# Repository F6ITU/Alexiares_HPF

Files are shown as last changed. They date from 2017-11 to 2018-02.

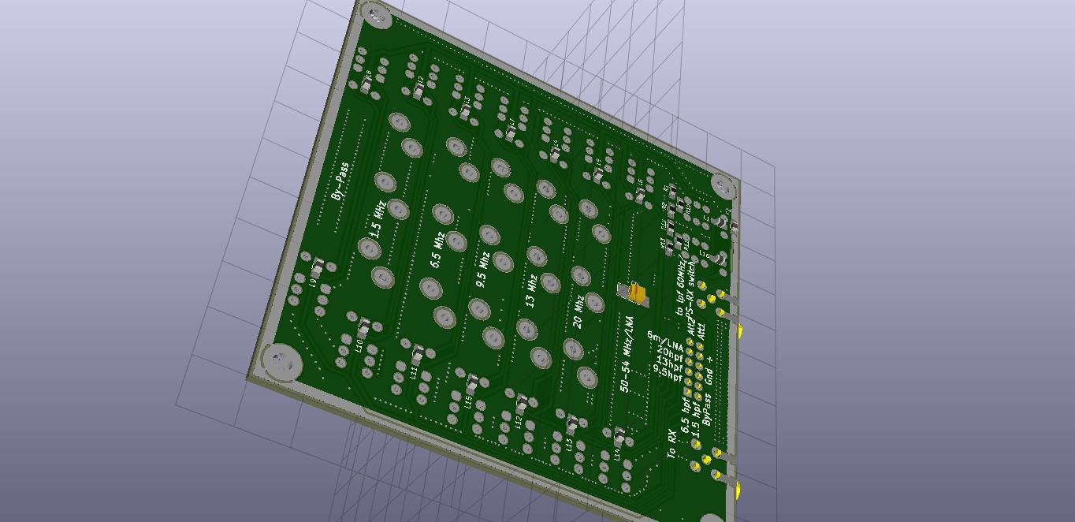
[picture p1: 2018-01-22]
HPF_bottom.jpg

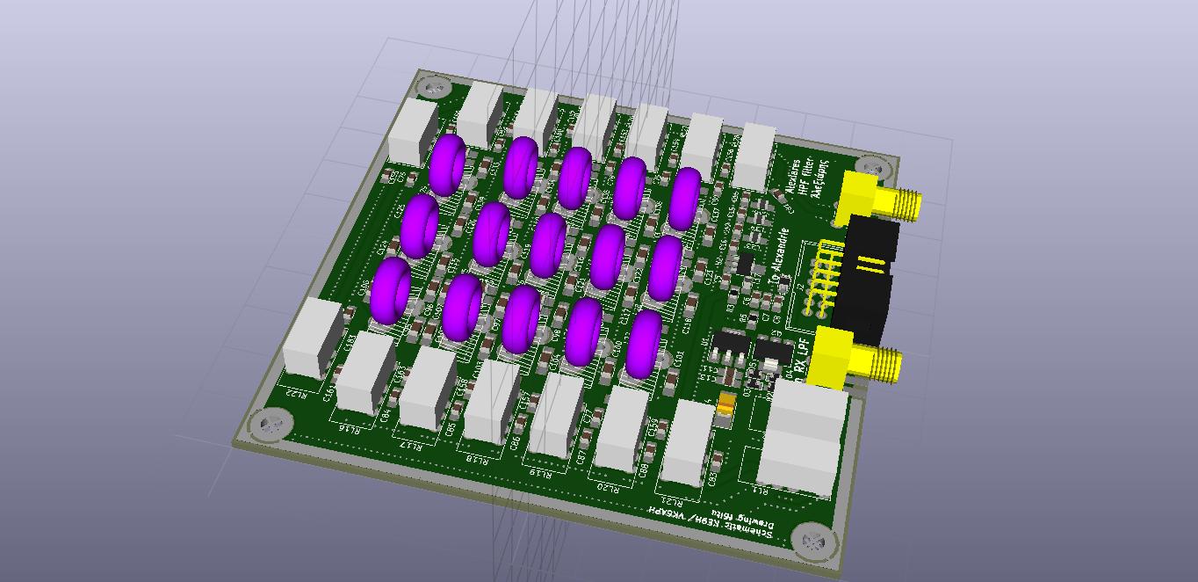
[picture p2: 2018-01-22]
HPF_top.jpg

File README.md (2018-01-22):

# Alexiares_HPF
This repository contains the High Pass Filter project of the OpenHPSDR Alexiares frontend

This work is protected by the TAPR Open Hardware Licence https://www.tapr.org/ohl.html

Original work by Graham Haddock, KE9H and Phil Harman, VK6APH.

for more informations, please refer to 

https://wiki.electrolab.fr/Projets:Lab:2017:Peripheriques_Angelia

3D image of the board are stored on this repo

HPF_top.jpg

HPF_bottom.jpg

Bom is available in CSV format

A separate BOM in XLS format is dedicated to filter capacitors

Note that ALL filter caps must be C0G or at least NP0 quality

Schematics, pcb design, modules and libs are in Kicad format

Gerber files are fully compatible with Protel 4.6 format

Board's dimensions are oversized to fit the 5x10 and 10x10cm size of all board of the Hermes project under Kicad:

* Alexandrie (Ἀλεξάνδρεια), Alexiares SPI interface
* Alexi2C ( Ἄλεξις), Alternate Alexiares I2C interface
* Alexiares_lpf (Ἀλεξιάρης) Alexiares low pass filter
* Alexiares_hpf (Ἀλεξιάρης) Alexiares high-pass filter
* Alexiares_Coax_Out (Ἀλεξιάρης ) Alexiares antenna switch boards
* Télémaque (Τηλέμαχος),  SSPA U/V/C°/Refl/FWD sensor for the Mentor board 
* Mentor (Μέντωρ) Micro-controler unit(MCU) and security module controling Telemaque informations
* Ulysse ou Odysseus (Ὀδυσσεύς), medium power reflectometer for the Telemaque/Mentor set
* Themis (Θέμις), low power bidirectionnal reflectometer with pre-distorsion (pure signal) output
* Aiôn (αἰών), 10 MHz low drift, low phase noise clock (general purpose)
* Hébé (Ἥβη), EER control system for high efficiency power amp

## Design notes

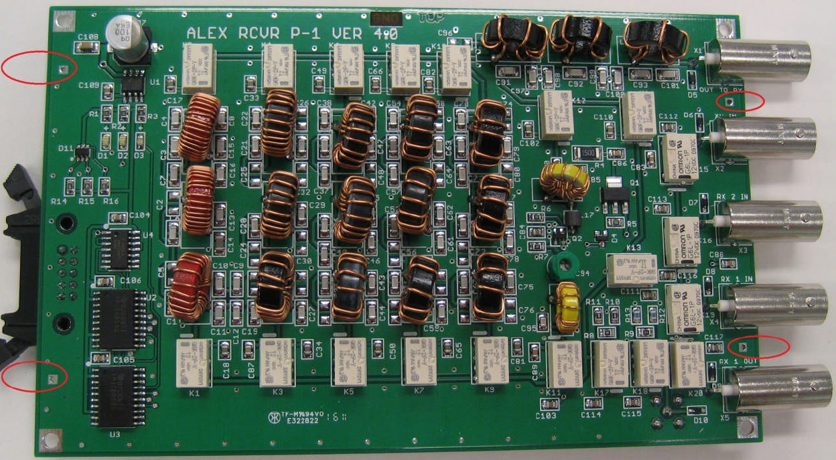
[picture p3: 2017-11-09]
Datasheet/alex hpf tapr.PNG

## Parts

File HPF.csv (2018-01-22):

Source: | C:/Users/Marco/Documents/Kicad/Projets/Alexiares_HPF/HPF.sch
Date: | 09/01/2018 09:03
Tool: | Eeschema 4.0.7
Generator: | C:/Program Files/KiCad/bin/scripting/plugins/bom_csv_grouped_by_value_with_fp.py
Component Count: | 174
Ref | Qnty | Value | Footprint
C7, | 1 | 100n | Capacitors_SMD:C_0805_HandSoldering
C8, | 1 | 1n | Capacitors_SMD:C_0805_HandSoldering
C9, C14, | 2 | 10uf | Capacitors_Tantalum_SMD:CP_Tantalum_Case-B_EIA-3528-21_Hand
C11, | 1 | 10p | Capacitors_SMD:C_0805_HandSoldering
C15, C12, | 2 | 60p | Capacitors_SMD:C_0805_HandSoldering
C16, C10, C13, | 3 | 100p | Capacitors_SMD:C_0805_HandSoldering
C81, C80, C79, C78, C77, C76, C159, C157, C158, C162, C161, C160, C82, C163, C156, C83, C155, C90, C154, C88, C153, C87, C152, C86, C151, C85, C150, C84, C4, C1, C3, C2, C5, C6, | 34 | 10n | Capacitors_SMD:C_0805_HandSoldering
C93, C116, C109, | 3 | 330p | Capacitors_SMD:C_1206_HandSoldering
C97, C107, C102, C96, C95, C183, | 6 | 2.2n | Capacitors_SMD:C_1206_HandSoldering
C98, C143, C144, C133, | 4 | 1.8n | Capacitors_SMD:C_1206_HandSoldering
C100, C115, C106, | 3 | 1.5n | Capacitors_SMD:C_1206_HandSoldering
C101, | 1 | 1.2n | Capacitors_SMD:C_1206_HandSoldering
C117, C137, C139, | 3 | 270p | Capacitors_SMD:C_1206_HandSoldering
C118, C94, C127, C110, C104, C103, | 6 | 220p | Capacitors_SMD:C_1206_HandSoldering
C121, | 1 | 100p | Capacitors_SMD:C_1206_HandSoldering
C123, C111, | 2 | 33p | Capacitors_SMD:C_1206_HandSoldering
C125, | 1 | 1n | Capacitors_SMD:C_1206_HandSoldering
C128, C140, | 2 | 68p | Capacitors_SMD:C_1206_HandSoldering
C129, C112, C120, | 3 | 180p | Capacitors_SMD:C_1206_HandSoldering
C130, C122, | 2 | 47p | Capacitors_SMD:C_1206_HandSoldering
C131, C113, | 2 | 120p | Capacitors_SMD:C_1206_HandSoldering
C132, C108, | 2 | 22p | Capacitors_SMD:C_1206_HandSoldering
C134, | 1 | 680 | Capacitors_SMD:C_1206_HandSoldering
C136, C126, | 2 | 390p | Capacitors_SMD:C_1206_HandSoldering
C145, C91, | 2 | 820p | Capacitors_SMD:C_1206_HandSoldering
C146, C124, | 2 | 680p | Capacitors_SMD:C_1206_HandSoldering
C147, | 1 | 68pC | Capacitors_SMD:C_1206_HandSoldering
C148, C135, C119, | 3 | 560p | Capacitors_SMD:C_1206_HandSoldering
C149, C92, | 2 | 470p | Capacitors_SMD:C_1206_HandSoldering
D1, | 1 | diode | Diodes_SMD:D_1206
D2, D3, D5, D4, | 4 | D | Diodes_SMD:D_0805
J2, | 1 | Conn_01x12 | Connect:IDC_Header_Straight_12pins
J3, J1, | 2 | CONN_COAXIAL | Connectors:SMA_THT_Jack_Straight
J5, J4, | 2 | CONN_COAXIAL | SMA_PINS:SMA_EDGE_NRW
L16, L2, L10, L5, L13, L3, L11, L4, L12, L7, L15, L6, L14, L8, L9, L1, | 16 | Choke | Inductors_SMD:L_0805_HandSoldering
L18, | 1 | 3.5u | T50:T50_V_THT
L19, | 1 | 1.14uH | T50:T50_V_THT
L21, | 1 | 562nH | T50:T50_V_THT
L22, | 1 | 311nH | T50:T50_V_THT
L23, L34, L35, L17, | 4 | 220n | Inductors_SMD:L_0805_HandSoldering
L28, | 1 | 434nH | T50:T50_V_THT
L29, L24, | 2 | 6.25u | T50:T50_V_THT
L30, L25, | 2 | 1.55uH | T50:T50_V_THT
L31, L26, | 2 | 940nH | T50:T50_V_THT
L32, L27, L20, | 3 | 650nH | T50:T50_V_THT
L33, | 1 | 511nH | T50:T50_V_THT
Q2, | 1 | zvp2106G | TO_SOT_Packages_SMD:SOT-223
R1, R2, | 2 | 100R | Resistors_SMD:R_0805_HandSoldering
R3, | 1 | 18 | Resistors_SMD:R_0805_HandSoldering
R5, | 1 | 10k | Resistors_SMD:R_0805_HandSoldering
R10, | 1 | 75R | Resistors_SMD:R_0805_HandSoldering
R11, | 1 | 240R | Resistors_SMD:R_0805_HandSoldering
R12, R13, | 2 | 62R | Resistors_SMD:R_0805_HandSoldering
RL28, RL27, RL29, RL26, RL25, RL24, RL23, RL16, RL17, RL18, RL19, RL20, RL21, RL22, RL2, RL1, | 16 | EC2-12 NU | 2_Form_C_Relay:Relay_DPDT_NEC_EC2
TP1, TP2, TP3, TP4, | 4 | TEST | Mounting_Holes:MountingHole_3.5mm_Pad
U1, | 1 | AP1117-50 | TO_SOT_Packages_SMD:SOT-223-3_TabPin2
U2, | 1 | PGA103+ | TO_SOT_Packages_SMD:SOT-89-3_Handsoldering

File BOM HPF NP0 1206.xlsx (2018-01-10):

Ref | Qty | Val | Footprint | Material
C93, C116, C109, | 3 | 330p | 1206 | Multilayer NP0/C0G
C97, C107, C102, C96, C95, C183, | 6 | 2.2n | 1206 | Multilayer NP0/C0G
C98, C143, C144, C133, | 4 | 1.8n | 1206 | Multilayer NP0/C0G
C100, C115, C106, | 3 | 1.5n | 1206 | Multilayer NP0/C0G
C101, | 1 | 1.2n | 1206 | Multilayer NP0/C0G
C117, C137, C139, | 3 | 270p | 1206 | Multilayer NP0/C0G
C118, C94, C127, C110, C104, C103, | 6 | 220p | 1206 | Multilayer NP0/C0G
C121, | 1 | 100p | 1206 | Multilayer NP0/C0G
C123, C111, | 2 | 33p | 1206 | Multilayer NP0/C0G
C125, | 1 | 1n | 1206 | Multilayer NP0/C0G
C128, C140, | 2 | 68p | 1206 | Multilayer NP0/C0G
C129, C112, C120, | 3 | 180p | 1206 | Multilayer NP0/C0G
C130, C122, | 2 | 47p | 1206 | Multilayer NP0/C0G
C131, C113, | 2 | 120p | 1206 | Multilayer NP0/C0G
C132, C108, | 2 | 22p | 1206 | Multilayer NP0/C0G
C134, | 1 | 680p | 1206 | Multilayer NP0/C0G
C136, C126, | 2 | 390p | 1206 | Multilayer NP0/C0G
C145, C91, | 2 | 820p | 1206 | Multilayer NP0/C0G
C146, C124, | 2 | 680p | 1206 | Multilayer NP0/C0G
C147, | 1 | 68pC | 1206 | Multilayer NP0/C0G
C148, C135, C119, | 3 | 560p | 1206 | Multilayer NP0/C0G
C149, C92, | 2 | 470p | 1206 | Multilayer NP0/C0G

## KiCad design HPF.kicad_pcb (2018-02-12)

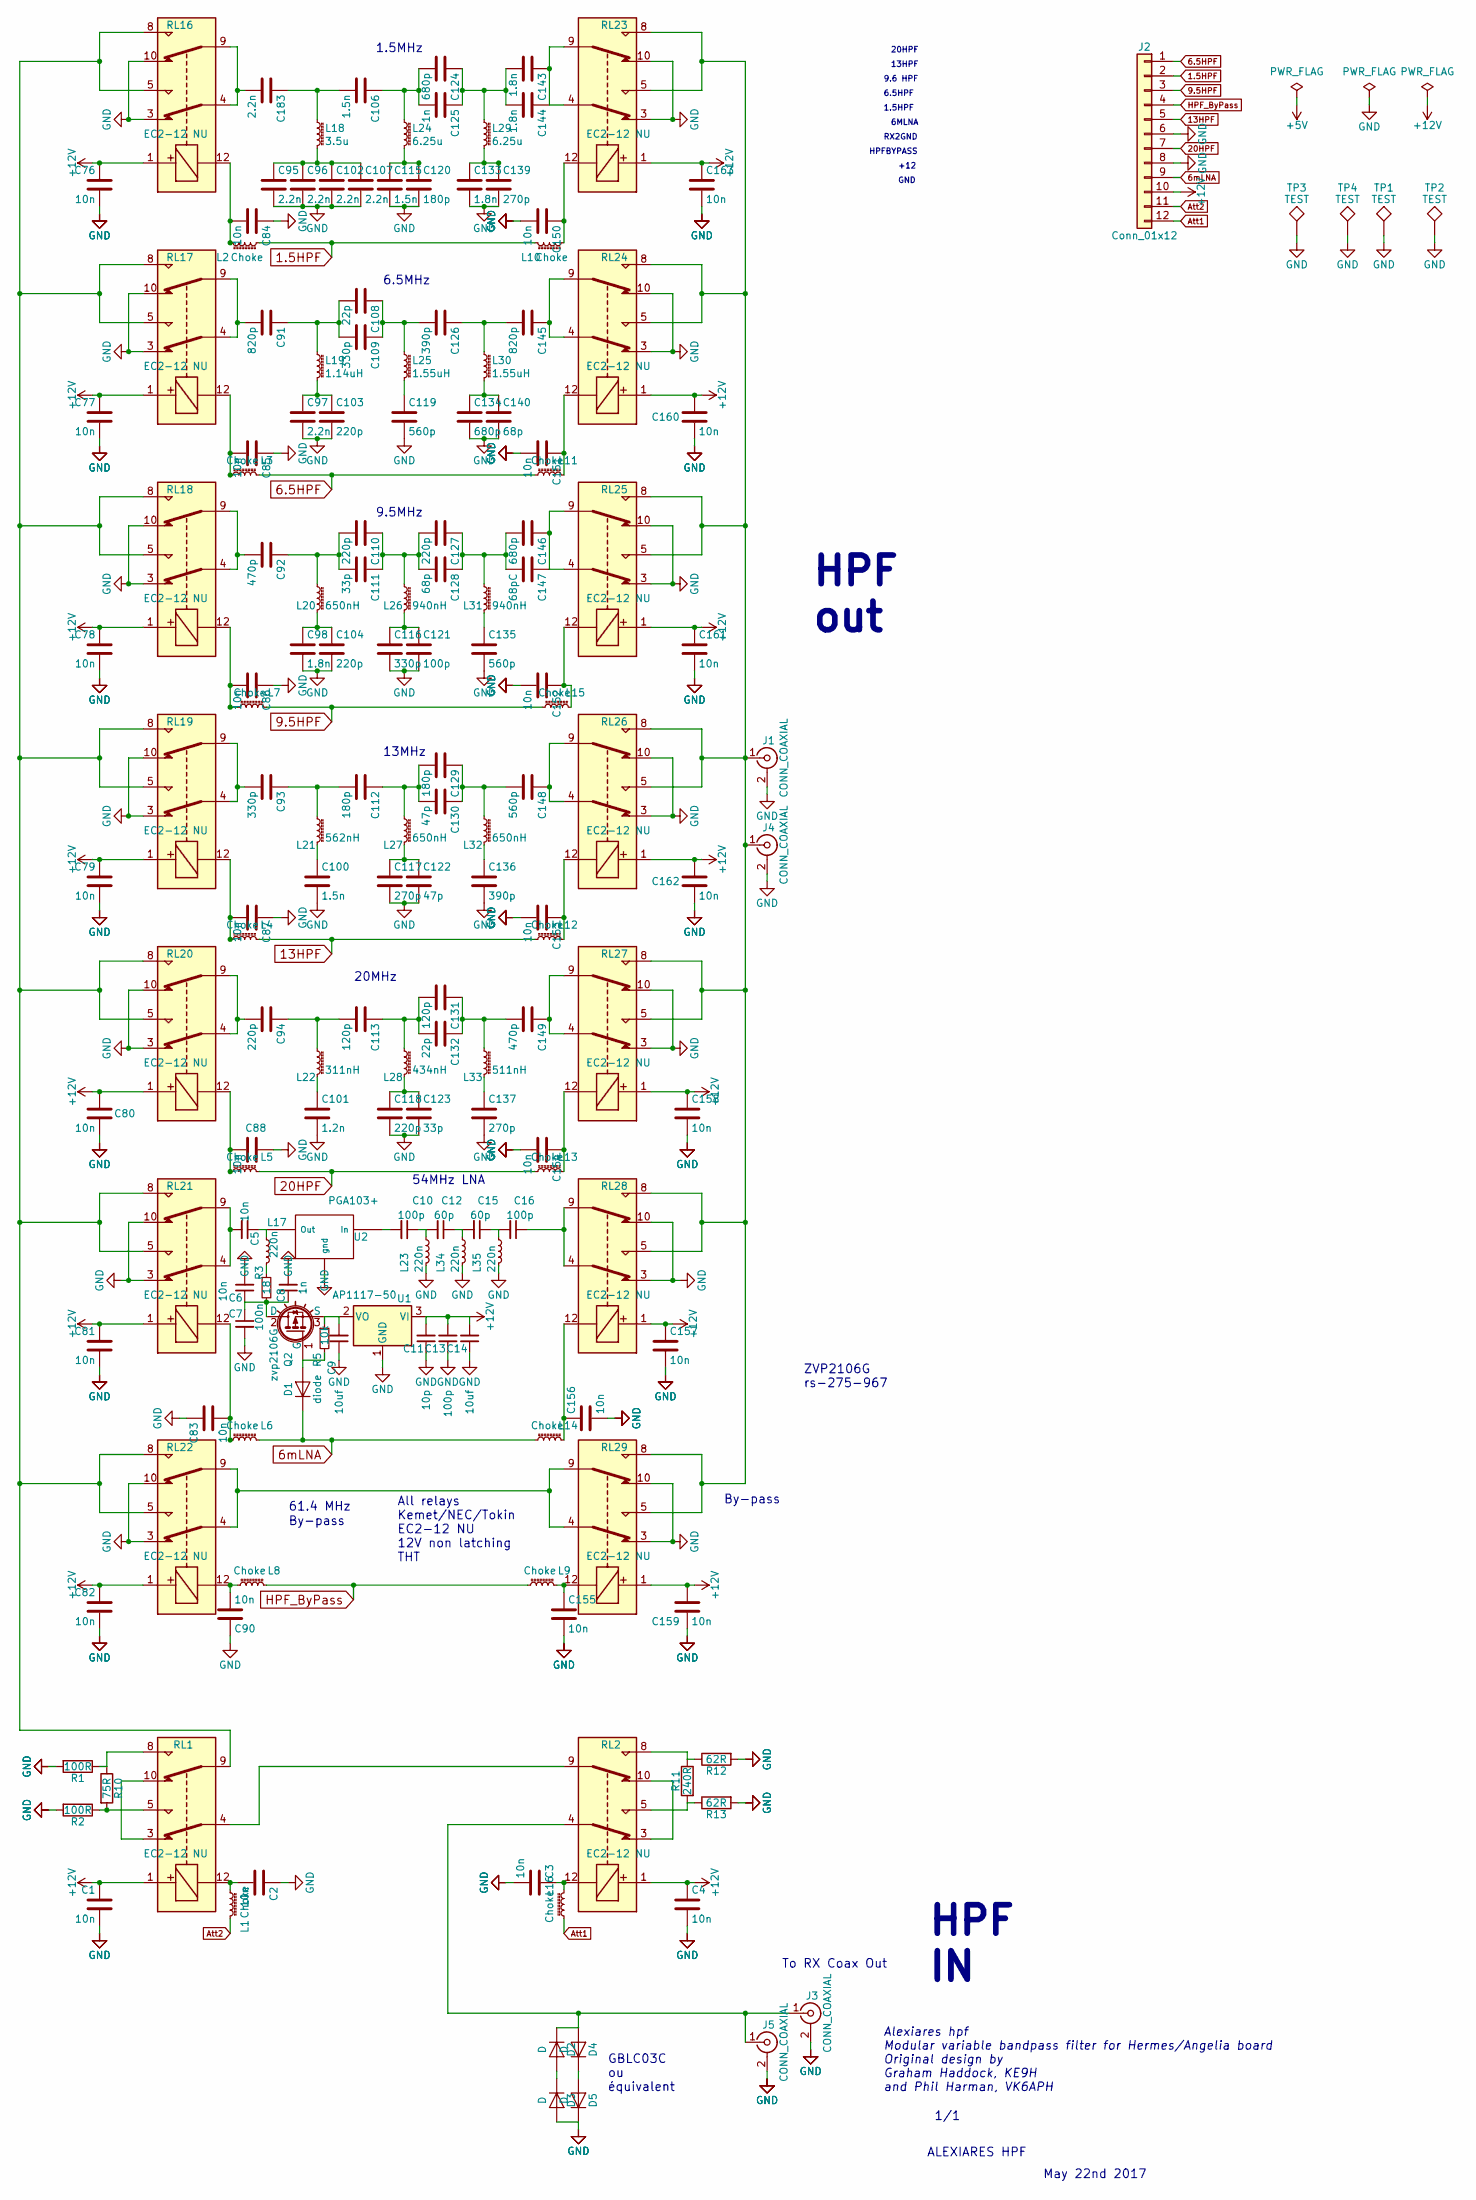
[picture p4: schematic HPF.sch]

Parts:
C1, C2, C3, C4, C5, C6, C76, C77, C78, C79, C80, C81, C82, C83, C84, C85, C86, C87, C88, C90, C150, C151, C152, C153, C154, C155, C156, C157, C158, C159, C160, C161, C162, C163: 10n; C_0805_HandSoldering
C7: 100n; C_0805_HandSoldering
C8: 1n; C_0805_HandSoldering
C9, C14: 10uf; CP_Tantalum_Case-B_EIA-3528-21_Hand
C10, C13, C16: 100p; C_0805_HandSoldering
C11: 10p; C_0805_HandSoldering
C12, C15: 60p; C_0805_HandSoldering
C91, C145: 820p; C_1206_HandSoldering
C92, C149: 470p; C_1206_HandSoldering
C93, C109, C116: 330p; C_1206_HandSoldering
C94, C103, C104, C110, C118, C127: 220p; C_1206_HandSoldering
C95, C96, C97, C102, C107, C183: 2.2n; C_1206_HandSoldering
C98, C133, C143, C144: 1.8n; C_1206_HandSoldering
C100, C106, C115: 1.5n; C_1206_HandSoldering
C101: 1.2n; C_1206_HandSoldering
C108, C132: 22p; C_1206_HandSoldering
C111, C123: 33p; C_1206_HandSoldering
C112, C120, C129: 180p; C_1206_HandSoldering
C113, C131: 120p; C_1206_HandSoldering
C117, C137, C139: 270p; C_1206_HandSoldering
C119, C135, C148: 560p; C_1206_HandSoldering
C121: 100p; C_1206_HandSoldering
C122, C130: 47p; C_1206_HandSoldering
C124, C134, C146: 680p; C_1206_HandSoldering
C125: 1n; C_1206_HandSoldering
C126, C136: 390p; C_1206_HandSoldering
C128, C140: 68p; C_1206_HandSoldering
C147: 68pC; C_1206_HandSoldering
D1: diode; D_1206
D2, D3, D4, D5: D; D_0805
J1, J3: CONN_COAXIAL; SMA_THT_Jack_Straight
J2: Conn_01x12; IDC_Header_Straight_12pins
J4, J5: CONN_COAXIAL; SMA_EDGE_NRW
L1, L2, L3, L4, L5, L6, L7, L8, L9, L10, L11, L12, L13, L14, L15, L16: Choke; L_0805_HandSoldering
L17, L23, L34, L35: 220n; L_0805_HandSoldering
L18: 3.5u; T50_V_THT
L19: 1.14uH; T50_V_THT
L20, L27, L32: 650nH; T50_V_THT
L21: 562nH; T50_V_THT
L22: 311nH; T50_V_THT
L24, L29: 6.25u; T50_V_THT
L25, L30: 1.55uH; T50_V_THT
L26, L31: 940nH; T50_V_THT
L28: 434nH; T50_V_THT
L33: 511nH; T50_V_THT
Q2: zvp2106G; SOT-223-3Lead_TabPin2
R1, R2: 100R; R_0805_HandSoldering
R3: 18; R_0805_HandSoldering
R5: 10k; R_0805_HandSoldering
R10: 75R; R_0805_HandSoldering
R11: 240R; R_0805_HandSoldering
R12, R13: 62R; R_0805_HandSoldering
RL1, RL2, RL16, RL17, RL18, RL19, RL20, RL21, RL22, RL23, RL24, RL25, RL26, RL27, RL28, RL29: EC2-12 NU; Relay_DPDT_NEC_EC2
TP1, TP2, TP3, TP4: TEST; MountingHole_3.5mm_Pad
U1: AP1117-50; SOT-223-3_TabPin2
U2: PGA103+; SOT-89-3_Handsoldering

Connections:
1.5HPF: J2.2, L2.1, L10.2
6.5HPF: J2.1, L3.2, L11.1
6mLNA: D1.1 (K), J2.9, L6.2, L14.1
9.5HPF: J2.3, L7.2, L15.1
13HPF: J2.5, L4.2, L12.1
20HPF: J2.7, L5.2, L13.1
+12V: C1.1, C4.1, C11.2, C13.2, C14.2, C76.1, C77.1, C78.1, C79.1, C80.1, C81.1, C82.1, C157.1, C158.1, C159.1, C160.1, C161.1, C162.1, C163.1, J2.10, RL1.1, RL2.1, RL16.1, RL17.1, RL18.1, RL19.1, RL20.1, RL21.1, RL22.1, RL23.1, RL24.1, RL25.1, RL26.1, RL27.1, RL28.1, RL29.1, U1.3 (VI)
Att1: J2.12, L16.1
Att2: J2.11, L1.2
GND: C1.2, C2.1, C3.2, C4.2, C6.2, C7.2, C8.2, C9.1, C11.1, C13.1, C14.1, C76.2, C77.2, C78.2, C79.2, C80.2, C81.2, C82.2, C83.1, C84.1, C85.1, C86.1, C87.1, C88.1, C90.1, C95.2, C96.2, C97.2, C98.2, C100.2, C101.2, C102.2, C103.2, C104.2, C107.2, C115.2, C116.2, C117.2, C118.2, C119.2, C120.2, C121.2, C122.2, C123.2, C133.2, C134.2, C135.2, C136.2, C137.2, C139.2, C140.2, C150.2, C151.2, C152.2, C153.2, C154.2, C155.2, C156.2, C157.2, C158.2, C159.2, C160.2, C161.2, C162.2, C163.2, D3.2 (A), D5.1 (K), J1.2 (Ext), J2.6, J2.8, J3.2 (Ext), J4.2 (Ext), J5.2 (Ext), L23.2, L34.2, L35.2, R1.2, R2.2, R12.2, R13.2, RL16.3, RL16.10, RL17.3, RL17.10, RL18.3, RL18.10, RL19.3, RL19.10, RL20.3, RL20.10, RL21.3, RL21.10, RL22.3, RL22.10, RL23.3, RL23.10, RL24.3, RL24.10, RL25.3, RL25.10, RL26.3, RL26.10, RL27.3, RL27.10, RL28.3, RL28.10, RL29.3, RL29.10, TP1.1, TP2.1, TP3.1, TP4.1, U1.1 (GND), U2.2 (gnd)
HPF_ByPass: J2.4, L8.2, L9.1
unnamed: C2.2, L1.1, RL1.12
unnamed: C3.1, L16.2, RL2.12
unnamed: C5.1, L17.1, U2.3 (Out)
unnamed: C5.2, RL21.4, RL21.9
unnamed: C6.1, C7.1, C8.1, Q2.2 (D), R3.2
unnamed: C9.2, Q2.3 (S), R5.1, U1.2 (VO)
unnamed: C10.1, C12.2, L23.1
unnamed: C10.2, U2.1 (In)
unnamed: C12.1, C15.2, L34.1
unnamed: C15.1, C16.2, L35.1
unnamed: C16.1, RL28.4, RL28.9
unnamed: C83.2, L6.1, RL21.12
unnamed: C84.2, L2.2, RL16.12
unnamed: C85.2, L3.1, RL17.12
unnamed: C86.2, L7.1, RL18.12
unnamed: C87.2, L4.1, RL19.12
unnamed: C88.2, L5.1, RL20.12
unnamed: C90.2, L8.1, RL22.12
unnamed: C91.2, RL17.4, RL17.9
unnamed: C92.2, RL18.4, RL18.9
unnamed: C93.2, RL19.4, RL19.9
unnamed: C94.2, RL20.4, RL20.9
unnamed: C100.1, L21.2
unnamed: C101.1, L22.2
unnamed: C95.1, C96.1, C102.1, C107.1, L18.2
unnamed: C97.1, C103.1, L19.2
unnamed: C98.1, C104.1, L20.2
unnamed: C106.1, C124.2, C125.2, L24.1
unnamed: C106.2, C183.1, L18.1
unnamed: C108.1, C109.1, C126.2, L25.1
unnamed: C91.1, C108.2, C109.2, L19.1
unnamed: C110.1, C111.1, C127.2, C128.2, L26.1
unnamed: C92.1, C110.2, C111.2, L20.1
unnamed: C112.1, C129.2, C130.2, L27.1
unnamed: C93.1, C112.2, L21.1
unnamed: C113.1, C131.2, C132.2, L28.1
unnamed: C94.1, C113.2, L22.1
unnamed: C115.1, C120.1, L24.2
unnamed: C116.1, C121.1, L26.2
unnamed: C117.1, C122.1, L27.2
unnamed: C118.1, C123.1, L28.2
unnamed: C119.1, L25.2
unnamed: C124.1, C125.1, C143.2, C144.2, L29.1
unnamed: C126.1, C145.2, L30.1
unnamed: C127.1, C128.1, C146.2, C147.2, L31.1
unnamed: C129.1, C130.1, C148.2, L32.1
unnamed: C131.1, C132.1, C149.2, L33.1
unnamed: C133.1, C139.1, L29.2
unnamed: C134.1, C140.1, L30.2
unnamed: C135.1, L31.2
unnamed: C136.1, L32.2
unnamed: C137.1, L33.2
unnamed: C143.1, C144.1, RL23.4, RL23.9
unnamed: C145.1, RL24.4, RL24.9
unnamed: C146.1, C147.1, RL25.4, RL25.9
unnamed: C148.1, RL26.4, RL26.9
unnamed: C149.1, RL27.4, RL27.9
unnamed: C150.1, L10.1, RL23.12
unnamed: C151.1, L11.2, RL24.12
unnamed: C152.1, L15.2, RL25.12
unnamed: C153.1, L12.2, RL26.12
unnamed: C154.1, L13.2, RL27.12
unnamed: C155.1, L9.2, RL29.12
unnamed: C156.1, L14.2, RL28.12
unnamed: C183.2, RL16.4, RL16.9
unnamed: D1.2 (A), Q2.1 (G), R5.2
unnamed: D2.1 (K), D4.2 (A), J3.1 (In), J5.1 (In), RL2.4
unnamed: D2.2 (A), D3.1 (K)
unnamed: D4.1 (K), D5.2 (A)
unnamed: J1.1 (In), J4.1 (In), RL23.5, RL23.8, RL24.5, RL24.8, RL25.5, RL25.8, RL26.5, RL26.8, RL27.5, RL27.8, RL28.5, RL28.8, RL29.5, RL29.8
unnamed: L17.2, R3.1
unnamed: R1.1, R10.1, RL1.8
unnamed: R2.1, R10.2, RL1.5
unnamed: R11.1, R12.1, RL2.8
unnamed: R11.2, R13.1, RL2.5
unnamed: RL1.4, RL2.9
unnamed: RL1.9, RL16.5, RL16.8, RL17.5, RL17.8, RL18.5, RL18.8, RL19.5, RL19.8, RL20.5, RL20.8, RL21.5, RL21.8, RL22.5, RL22.8
unnamed: RL1.3, RL1.10
unnamed: RL2.3, RL2.10
unnamed: RL22.4, RL22.9, RL29.4, RL29.9

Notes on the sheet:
Alexiares hpf Modular variable bandpass filter for Hermes/Angelia board Original design by Graham Haddock, KE9H and Phil Harman, VK6APH
1/1
ALEXIARES HPF
May 22nd 2017
HPF IN
HPF out
61.4 MHz
All relays Kemet/NEC/Tokin EC2-12 NU 12V non latching THT
By-pass
54MHz LNA
20MHz
13MHz
9.5MHz
6.5MHz
1.5MHz
20HPF
13HPF
9.6 HPF
6.5HPF
1.5HPF
6MLNA
RX2GND
HPFBYPASS
+12
GND
To RX Coax Out
GBLC03C ou équivalent
ZVP2106G rs-275-967

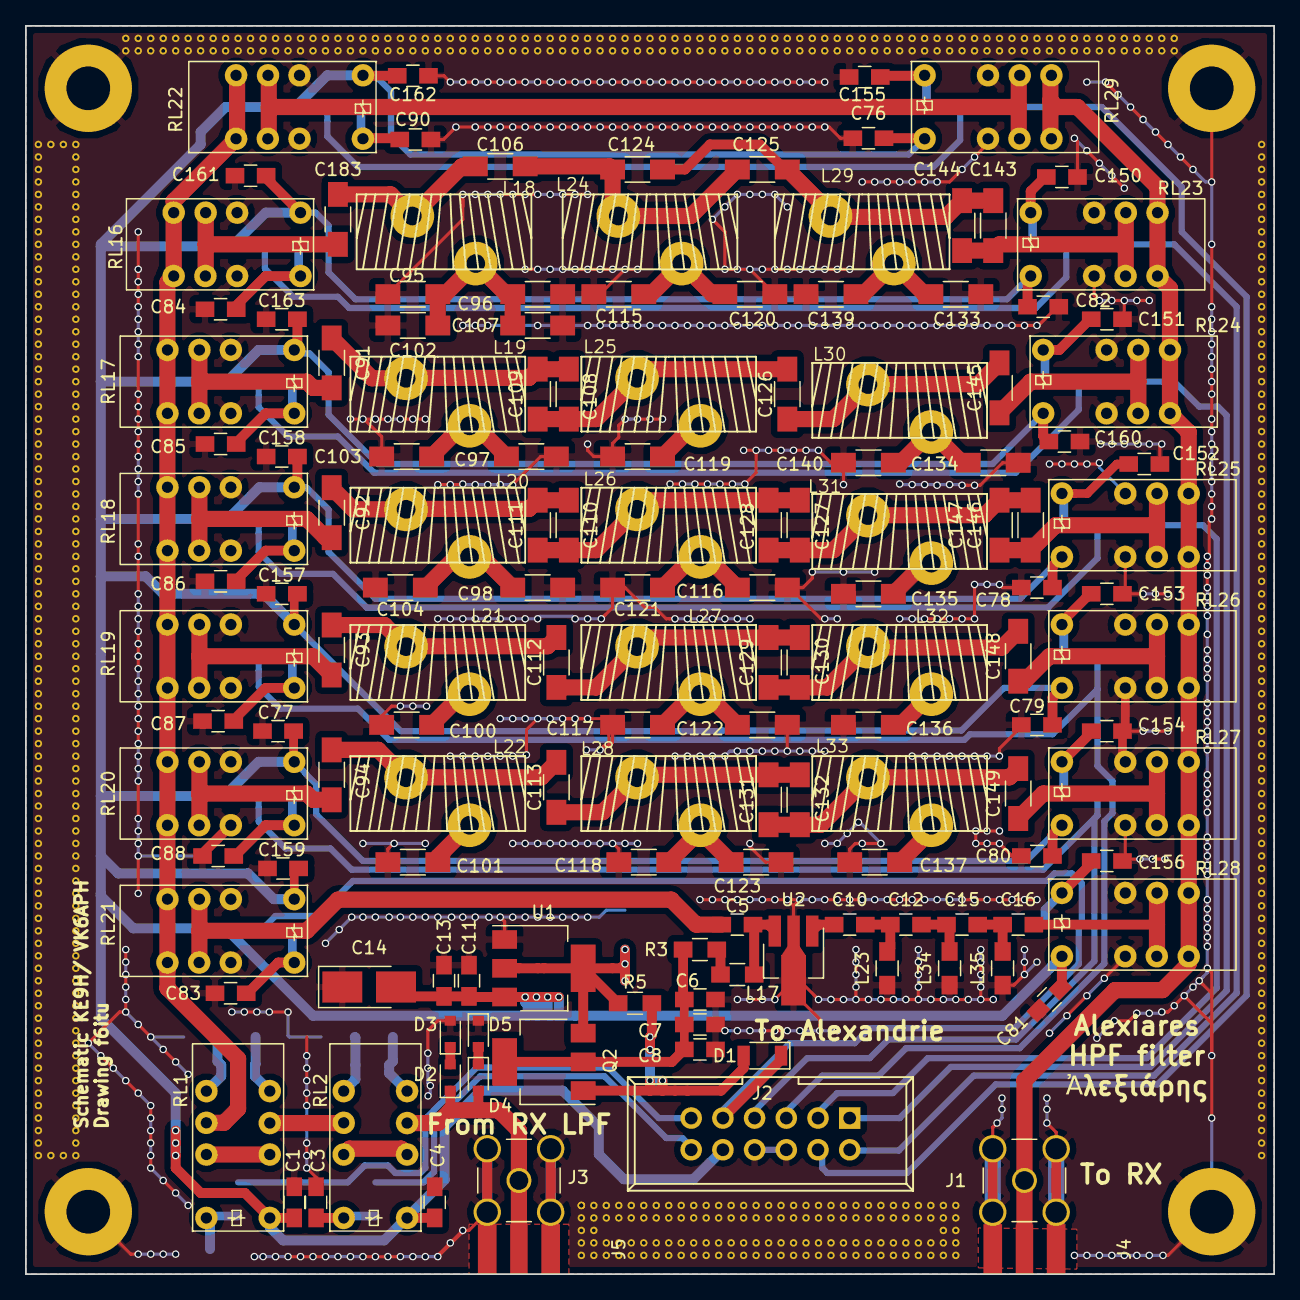
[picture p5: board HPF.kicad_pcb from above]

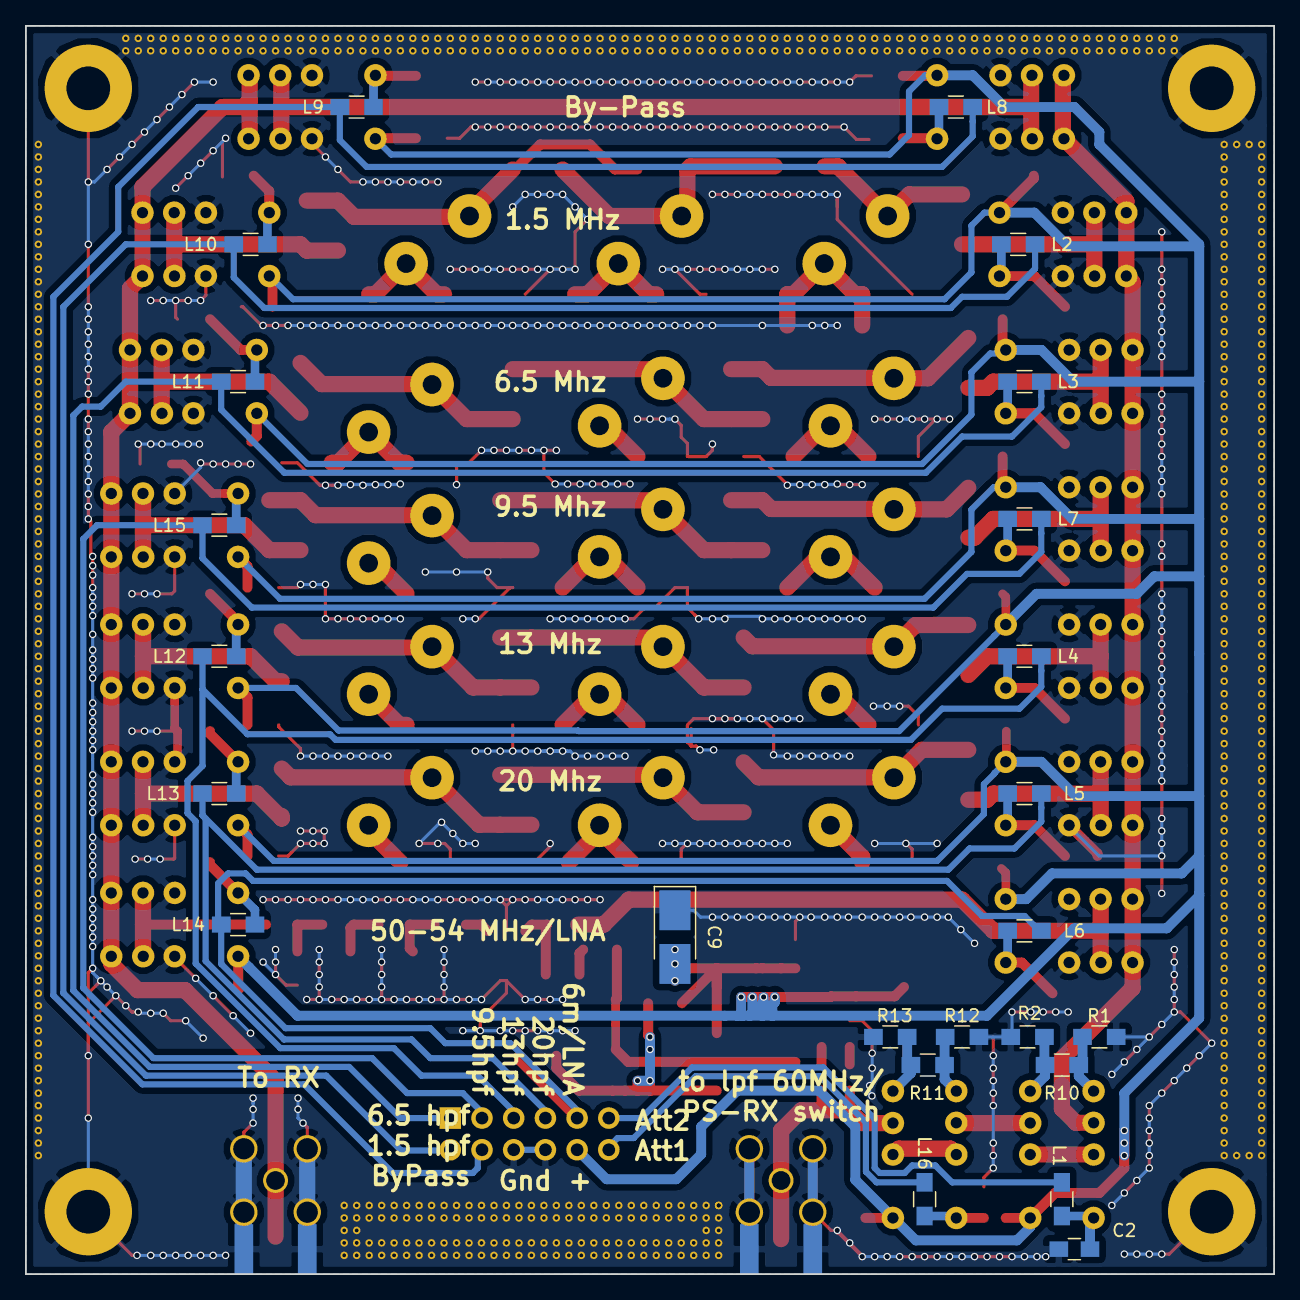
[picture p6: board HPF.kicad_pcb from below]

Board: 4 copper layers, 100.0 x 100.0 mm, 174 parts (24 on the bottom side), 91 nets.

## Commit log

2017-06-12 hpf V1.0, compatible w OpenHPSDR Ver24
    [HPF.kicad_pcb, HPF.sch]
2017-11-09 firt routing, 6m LPF discarted
    [HPF.kicad_pcb, HPF.sch]
2017-11-12 silkmask cleanup and comments added
    [HPF.kicad_pcb, HPF.sch]
2017-11-14 New LNA, silkmask modified
    [HPF.kicad_pcb, HPF.sch]
2017-11-27 new ferrite footprint/module
2017-12-12 edge SMA added, main connector shifted
    [HPF.kicad_pcb, HPF.sch]
2017-12-16 changed sma footprint, gerber done
    [HPF-B.Adhes.gbr, HPF-B.Cu.gbl, HPF-B.Cu.gbr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]
2018-01-06 new stitching, new gerber
    [HPF-B.Adhes.gbr, HPF-B.Cu.gbl, HPF-B.Cu.gbr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]
2018-01-09 BOM added, new Gerber
    [Bom cap filter.xlsx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]
2018-01-10 silkmask mods,, gnd stitching cleaning, gerber added
    [BOM HPF NP0 1206.xlsx, Bom cap filter.xlsx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]
2018-01-13 minor changes, new gerber
    [HPF-B.Cu.gbl, HPF-B.Mask.gbs, HPF-B.SilkS.gbo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]
2018-01-14 Bad MosFET footprint corrected, new gerber
    [HPF-B.Cu.gbl, HPF-B.Mask.gbs, HPF-B.SilkS.gbo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]
2018-01-22 new gerber
    [HPF.csv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]
2018-02-12 some stiching error fixed
    [HPF.kicad_pcb]
